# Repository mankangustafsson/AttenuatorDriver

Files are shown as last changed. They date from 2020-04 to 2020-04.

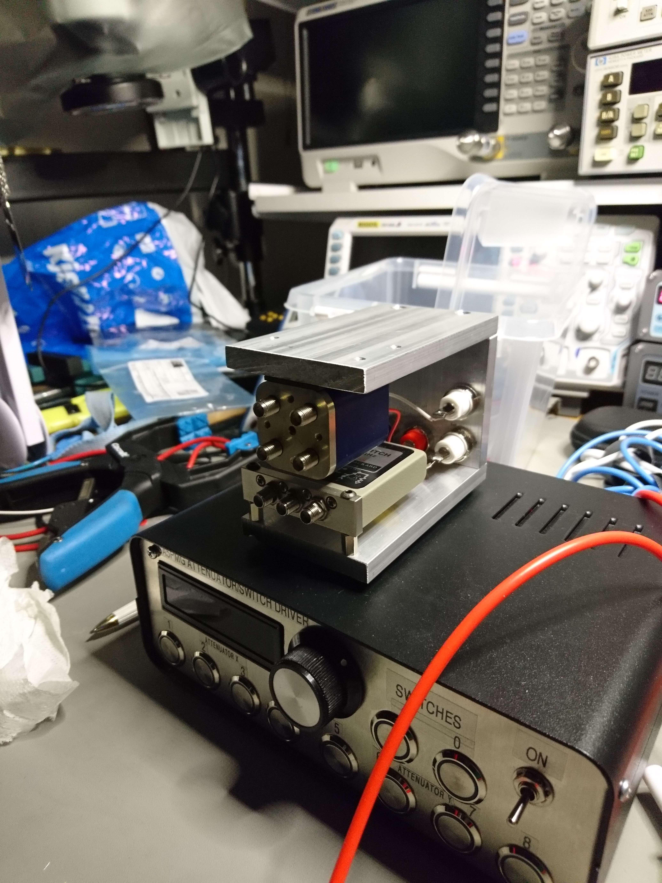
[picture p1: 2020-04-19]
gallery/build 16 relay holder done.JPG

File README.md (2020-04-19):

# AttenuatorDriver
Attenuator switch and relay driver similar to HP11713A/B. This project covers many firsts for me: First project using KiCad, first project published on github, first Python code (GPIB control) so please bear with me.

## Hardware
The HW design started out with the solenoid control of the attenuator switches inspired by the HP 33311 product overview pdf. After a while I decided to not care about the TTL output part and just trust the LED indicators.

Each attenuator solenoid is controlled by two ULN2803 outputs. 8 attenuators in total thus requires all outputs in two ULN2803:s.

To control coaxial relays I wanted to be able to handle latching relays that is controlled by polarity switching the coil voltage. For that task I found the SN754410 Quad Half-H Driver from Texas Instruments. There are cheaper circuits that can achieve this but this is the only one I found that could handle 28V coils.

To keep the micro controller I/O pin count as low as possible I decided to control the attenuators and relays drive circuits with plain old shift registers. So three 74HC595 gets the 24 output pin count down to just four.

I also wanted to keep my options open to which kind of display I would use, so that is why both I2C and SPI connectors are available. I ended up with an LCD1602 controlled via I2C. For input I wanted to mimic the HP 11713A so I wanted 10 push buttons so two R2R ladders handles five buttons each. But I also wanted to utilize the display and I find using rotary encoders with a push button quite powerful to navigate a simple UI.

### Power Supply
This can be improved but the current design works for me. The HW is fed with 12VDC and 24VDC to the ULN2803 controlling the first four attenuators. The second set of attenuators and the relays can also be feed directly with this 24V supply. Or they can have a lower voltage controlled by their individual LM317 voltage regulator. This mean that the first attenuator group decides the highest voltage that the other atteunators and relays can use.

To remedy this I would put one extra LM317 to control the voltage to the first attenuator group and remove the J6 and J7 jumpers. This way each attenuator group and the relay pair could have their coils voltages individually set.

### Patches
I made the faulty assumption about coaxial relays could control the LED the same way the attenuators did. They do not! So the remedy is to use two free micro controller pins (I use A1 and A2) to control the relay LED indicators. Depending on LEDs used the micro controller could probably drive them directly or you could still use Q3 and Q4 to sink the current. Regardless solution you select you need to remove R4 and R6.

## Arduino Software
First of all: Do not expect any compilation support from me. You are on your own. Arduino environment is messy when it comes to how it handles libraries used. I usually import the source code of the libraries I use into the project. However since I'm not the author of the [display library] I use you have to download it yourself. The current code also includes another library, Streaming, which I only used initially in this project so remove that include statement.

Second: Parts of the code is structured and easy to read. Some parts are not structured at all and poorly documented. I'm of the opinion that code should be written to be easy to understand by other programmers and therefore would not need much documentation. It is not currently in the "easy to understand" state and it might never be.

## GPIB Control
In order to avoid the Arduino being reset every time you connect to the serial port, you need to remove the capacitor between the CH340 DTR pin and the Arduino reset pin. Note that this will make it harder to upload new software to the Arduino. You will need to push the reset button manually at the proper moment during code upload.

I've written some Python code using PyVisa to control the attenuators and relays.

[display library]:       http://www.mathertel.de/Arduino/LiquidCrystal_PCF8574.aspx

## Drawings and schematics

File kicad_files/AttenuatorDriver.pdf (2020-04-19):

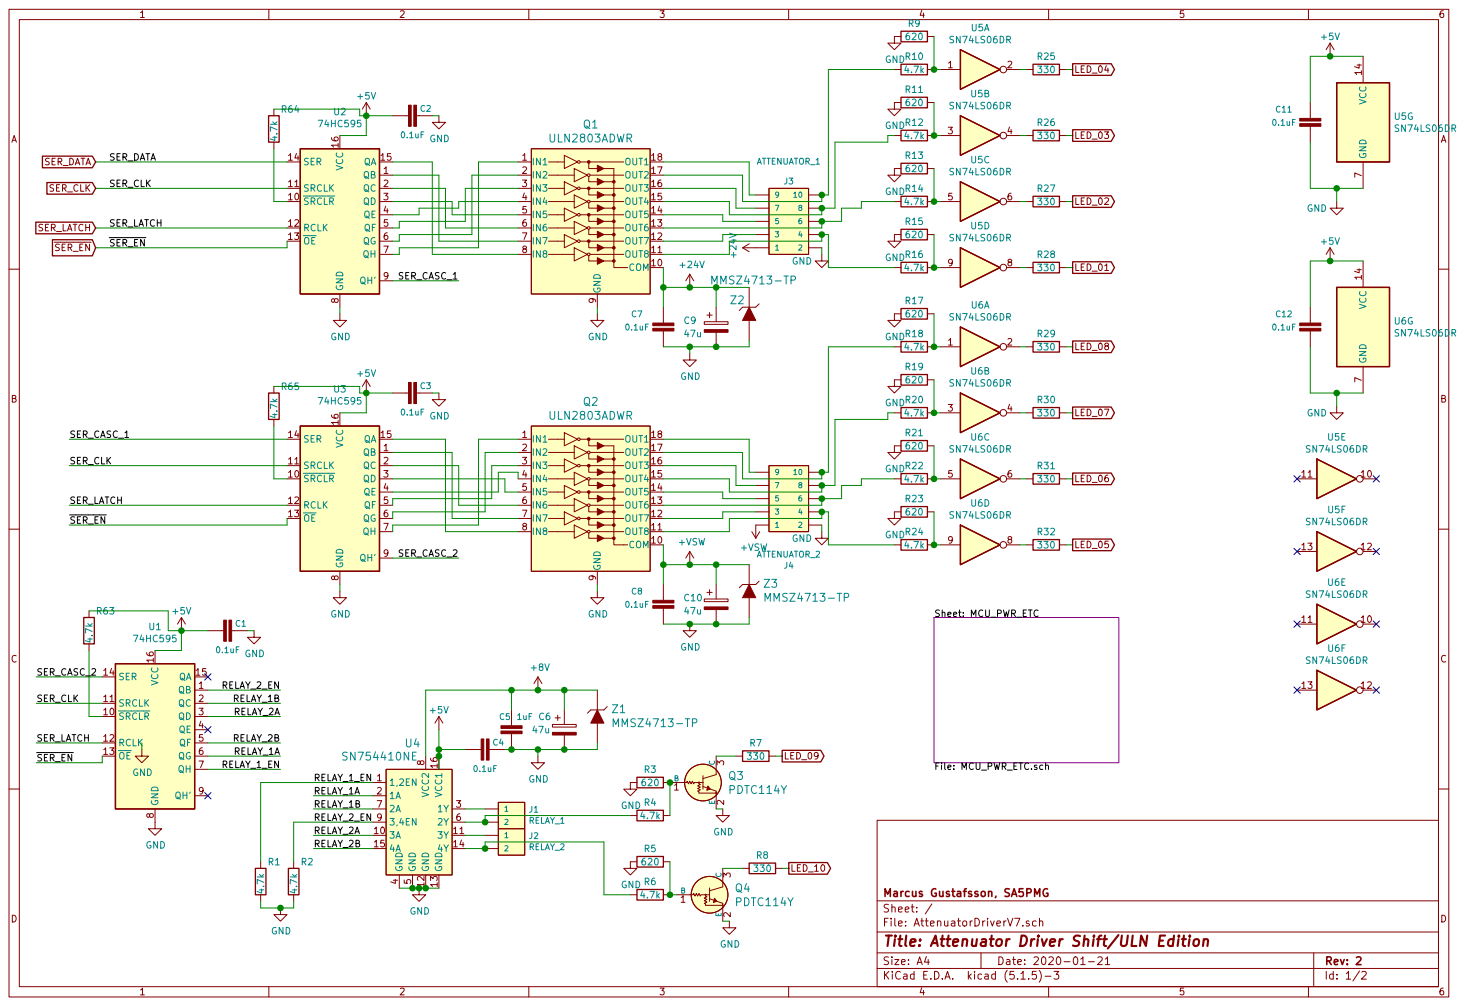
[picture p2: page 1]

File: AttenuatorDriverV7.sch Sheet: / Marcus Gustafsson, SA5PMG

Id: 1/2 Title: Attenuator Driver Shift/ULN Edition

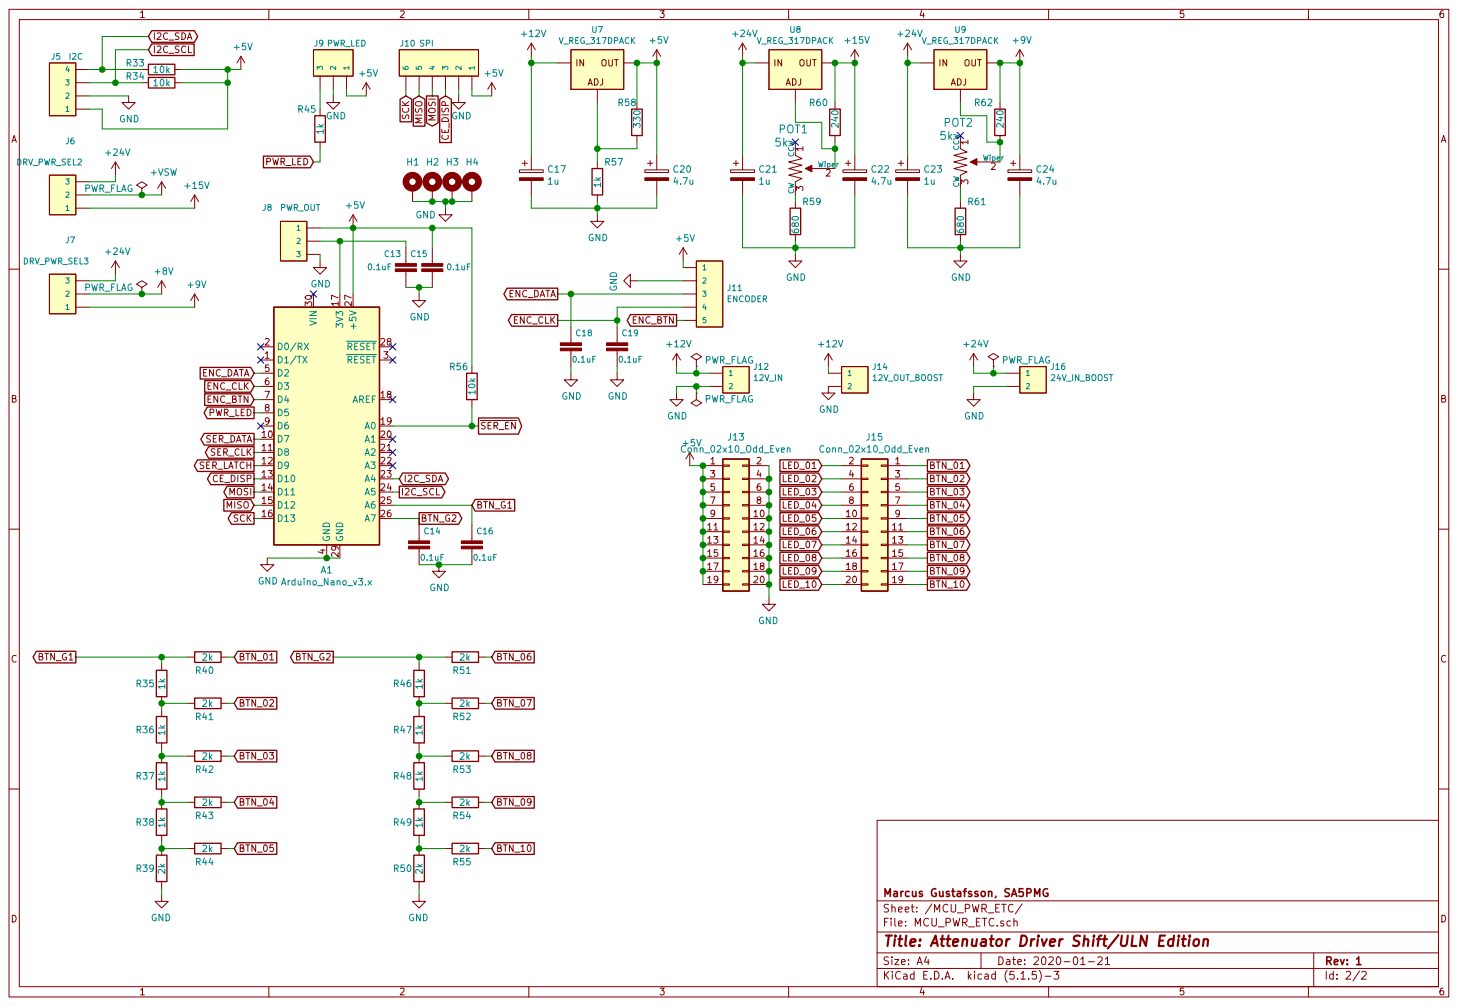
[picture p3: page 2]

11 | 12
13 | 14
15 | 16
17 | 18

Marcus Gustafsson, SA5PMG
Sheet: /MCU_PWR_ETC/
File: MCU_PWR_ETC.sch
Id: 2/2 Title: Attenuator Driver Shift/ULN Edition

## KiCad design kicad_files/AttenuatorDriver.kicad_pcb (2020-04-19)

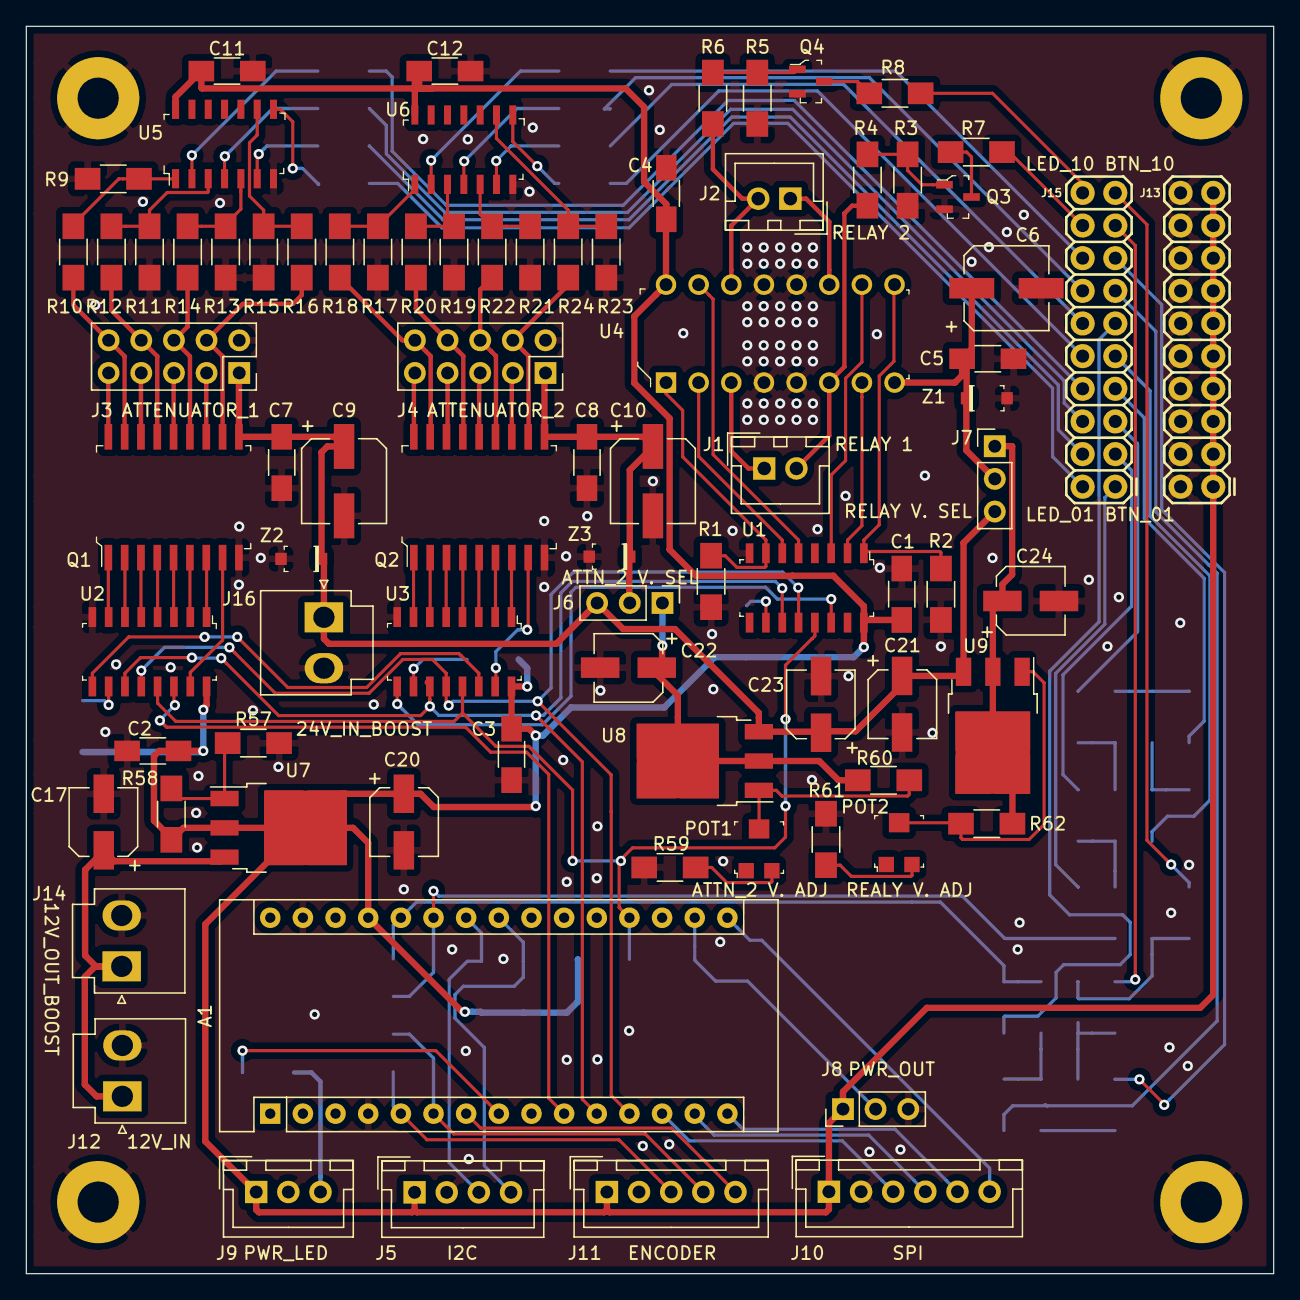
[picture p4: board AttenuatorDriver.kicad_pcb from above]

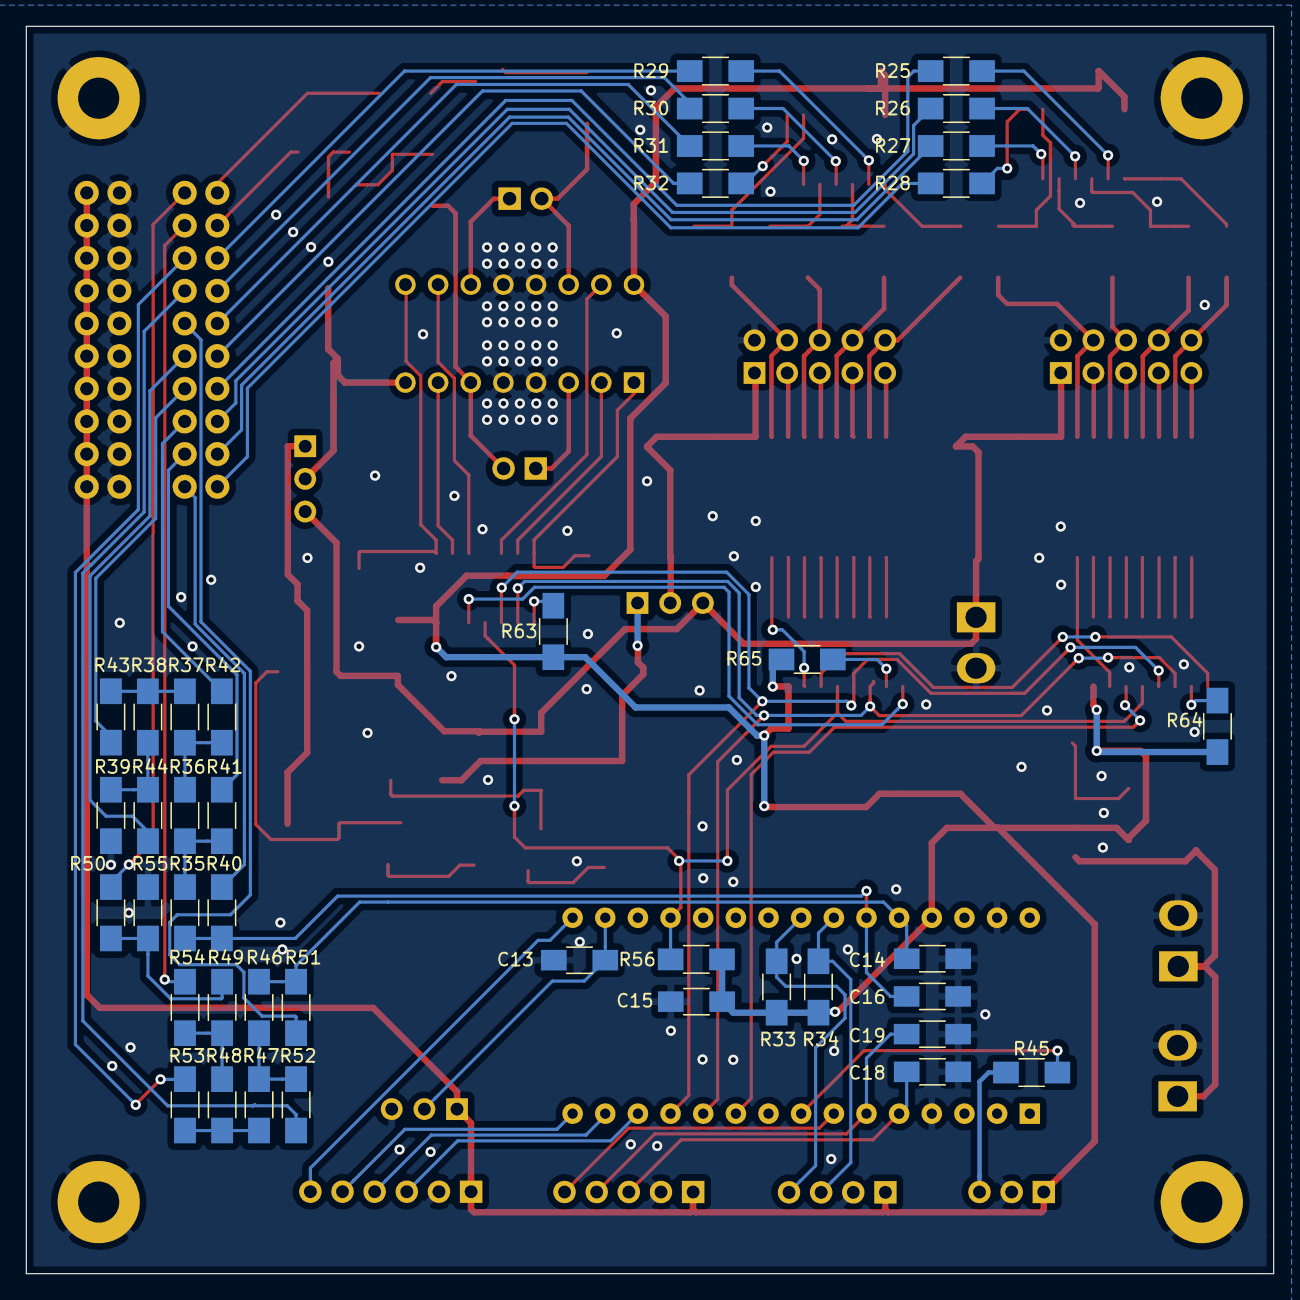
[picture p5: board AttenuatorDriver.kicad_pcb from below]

Board: 2 copper layers, 97.0 x 97.0 mm, 128 parts (41 on the bottom side), 126 nets.

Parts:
A1: Arduino_Nano_v3.x; Arduino_Nano
C1, C2, C3, C4, C7, C8, C11, C12, C13, C14, C15, C16, C18, C19: 0.1uF; C_1206_HandSoldering
C5: 1uF; C_1206_HandSoldering
C6, C9, C10: 47u; CP_Elec_6.3x7.7
C17, C21, C23: 1u; CP_Elec_5x5.3
C20, C22, C24: 4.7u; CP_Elec_5x5.3
H1, H2, H3, H4: MountingHole_Pad; MountingHole_3.2mm_M3_Pad
J1: RELAY_1; JST_XH_B02B-XH-A_02x2.50mm_Straight
J2: RELAY_2; JST_XH_B02B-XH-A_02x2.50mm_Straight
J3: ATTENUATOR_1; Socket_Strip_Straight_2x05_Pitch2.54mm
J4: ATTENUATOR_2; Socket_Strip_Straight_2x05_Pitch2.54mm
J5: I2C; JST_XH_B04B-XH-A_04x2.50mm_Straight
J6: DRV_PWR_SEL2; Pin_Header_Straight_1x03_Pitch2.54mm
J7: DRV_PWR_SEL3; Pin_Header_Straight_1x03_Pitch2.54mm
J8: PWR_OUT; Pin_Header_Straight_1x03_Pitch2.54mm
J9: PWR_LED; JST_XH_B03B-XH-A_03x2.50mm_Straight
J10: SPI; JST_XH_B06B-XH-A_06x2.50mm_Straight
J11: ENCODER; JST_XH_B05B-XH-A_05x2.50mm_Straight
J12: 12V_IN; JST_VH_B2P-VH-B_2x3.96mm_Vertical
J13, J15: Conn_02x10_Odd_Even; 2X10
J14: 12V_OUT_BOOST; JST_VH_B2P-VH-B_2x3.96mm_Vertical
J16: 24V_IN_BOOST; JST_VH_B2P-VH-B_2x3.96mm_Vertical
POT1, POT2: 5k; Trimpot_3.8mmx3.6mm_TC33X-2-103E
Q1, Q2: ULN2803ADWR; SOIC-18_W7.5mm
Q3, Q4: PDTC114Y; SOT-23-3
R1, R2, R4, R6, R10, R12, R14, R16, R18, R20, R22, R24, R63, R64, R65: 4.7k; R_1206_HandSoldering
R3, R5, R9, R11, R13, R15, R17, R19, R21, R23: 620; R_1206_HandSoldering
R7, R8, R25, R26, R27, R28, R29, R30, R31, R32, R58: 330; R_1206_HandSoldering
R33, R34, R56: 10k; R_1206_HandSoldering
R35, R36, R37, R38, R45, R46, R47, R48, R49, R57: 1k; R_1206_HandSoldering
R39, R40, R41, R42, R43, R44, R50, R51, R52, R53, R54, R55: 2k; R_1206_HandSoldering
R59, R61: 680; R_1206_HandSoldering
R60, R62: 240; R_1206_HandSoldering
U1, U2, U3: 74HC595; SOIC-16_W3.90mm
U4: SN754410NE; DIP-16_W7.62mm
U5, U6: SN74LS06DR; SOIC-14_W3.9mm
U7, U8, U9: V_REG_317DPACK; TO-252-3_TabPin2
Z1, Z2, Z3: MMSZ4713-TP; SOD-123

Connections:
+5V: A1.27, C1.1, C2.1, C3.1, C4.1, C11.1, C12.1, C15.2, C20.1, J5.1, J8.1, J9.1, J10.1, J11.1, J13.1, J13.3, J13.5, J13.7, J13.9, J13.11, J13.13, J13.15, J13.17, J13.19, R33.1, R34.1, R56.1, R58.1, R63.1, R64.1, R65.1, U1.16, U2.16, U3.16, U4.16, U5.14, U6.14, U7.2
+8V: C5.1, C6.1, J7.2, U4.8, Z1.K
+9V: C24.1, J7.1, R62.1, U9.2
+12V: C17.1, J12.1, J14.1, U7.3
+15V: C22.1, J6.1, R60.1, U8.2
+24V: C7.1, C9.1, C21.1, C23.1, J3.1, J6.3, J7.3, J16.1, Q1.10, U8.3, U9.3, Z2.K
+VSW: C8.1, C10.1, J4.1, J6.2, Q2.10, Z3.K
/RELAY_1A: U1.6, U4.2
/RELAY_1B: U1.2, U4.7
/RELAY_1_EN: R1.1, U1.7, U4.1
/RELAY_2A: U1.3, U4.10
/RELAY_2B: U1.5, U4.15
/RELAY_2_EN: R2.1, U1.1, U4.9
/SER_CASC_1: U2.9, U3.14
/SER_CASC_2: U1.14, U3.9
BTN_01: J15.1, R40.1
BTN_02: J15.3, R41.1
BTN_03: J15.5, R42.1
BTN_04: J15.7, R43.1
BTN_05: J15.9, R44.1
BTN_06: J15.11, R51.1
BTN_07: J15.13, R52.1
BTN_08: J15.15, R53.1
BTN_09: J15.17, R54.1
BTN_10: J15.19, R55.1
BTN_G1: A1.25, C16.2, R35.1, R40.2
BTN_G2: A1.26, C14.2, R46.1, R51.2
CE_DISP: A1.13, J10.3
ENC_BTN: A1.7, J11.5
ENC_CLK: A1.6, C19.2, J11.4
ENC_DATA: A1.5, C18.2, J11.3
GND: A1.4, A1.29, C1.2, C2.2, C3.2, C4.2, C5.2, C6.2, C7.2, C8.2, C9.2, C10.2, C11.2, C12.2, C13.1, C14.1, C15.1, C16.1, C17.2, C18.1, C19.1, C20.2, C21.2, C22.2, C23.2, C24.2, H1.1, H2.1, H3.1, H4.1, J3.2, J4.2, J5.2, J8.3, J9.2, J10.2, J11.2, J12.2, J13.2, J13.4, J13.6, J13.8, J13.10, J13.12, J13.14, J13.16, J13.18, J13.20, J14.2, J16.2, Q1.9, Q2.9, Q3.2, Q4.2, R1.2, R2.2, R3.2, R5.2, R9.2, R11.2, R13.2, R15.2, R17.2, R19.2, R21.2, R23.2, R39.2, R50.2, R57.2, R59.2, R61.2, U1.8, U2.8, U3.8, U4.4, U4.5, U4.12, U4.13, U5.7, U6.7, Z1.A, Z2.A, Z3.A
I2C_SCL: A1.24, J5.3, R34.2
I2C_SDA: A1.23, J5.4, R33.2
LED_01: J15.2, R28.1
LED_02: J15.4, R27.1
LED_03: J15.6, R26.1
LED_04: J15.8, R25.1
LED_05: J15.10, R32.1
LED_06: J15.12, R31.1
LED_07: J15.14, R30.1
LED_08: J15.16, R29.1
LED_09: J15.18, R7.1
LED_10: J15.20, R8.1
MISO: A1.15, J10.5
MOSI: A1.14, J10.4
unnamed: A1.17, C13.2, J8.2
unnamed: J1.1, U4.3
unnamed: J1.2, R4.2, U4.6
unnamed: J2.1, U4.11
unnamed: J2.2, R6.2, U4.14
unnamed: J3.3, Q1.12
unnamed: J3.4, Q1.11, R16.2
unnamed: J3.5, Q1.14
unnamed: J3.6, Q1.13, R14.2
unnamed: J3.7, Q1.16
unnamed: J3.8, Q1.15, R12.2
unnamed: J3.9, Q1.18
unnamed: J3.10, Q1.17, R10.2
unnamed: J4.3, Q2.12
unnamed: J4.4, Q2.11, R24.2
unnamed: J4.5, Q2.14
unnamed: J4.6, Q2.13, R22.2
unnamed: J4.7, Q2.16
unnamed: J4.8, Q2.15, R20.2
unnamed: J4.9, Q2.18
unnamed: J4.10, Q2.17, R18.2
unnamed: J9.3, R45.1
unnamed: POT1.2, R60.2, U8.1
unnamed: POT1.3, R59.1
unnamed: POT2.2, R62.2, U9.1
unnamed: POT2.3, R61.1
unnamed: Q1.1, U2.7
unnamed: Q1.2, U2.6
unnamed: Q1.3, U2.5
unnamed: Q1.4, U2.4
unnamed: Q1.5, U2.3
unnamed: Q1.6, U2.2
unnamed: Q1.7, U2.1
unnamed: Q1.8, U2.15
unnamed: Q2.1, U3.7
unnamed: Q2.2, U3.6
unnamed: Q2.3, U3.5
unnamed: Q2.4, U3.4
unnamed: Q2.5, U3.3
unnamed: Q2.6, U3.2
unnamed: Q2.7, U3.1
unnamed: Q2.8, U3.15
unnamed: Q3.1, R3.1, R4.1
unnamed: Q3.3, R7.2
unnamed: Q4.1, R5.1, R6.1
unnamed: Q4.3, R8.2
unnamed: R9.1, R10.1, U5.1
unnamed: R11.1, R12.1, U5.3
unnamed: R13.1, R14.1, U5.5
unnamed: R15.1, R16.1, U5.9
unnamed: R17.1, R18.1, U6.1
unnamed: R19.1, R20.1, U6.3
unnamed: R21.1, R22.1, U6.5
unnamed: R23.1, R24.1, U6.9
unnamed: R25.2, U5.2
unnamed: R26.2, U5.4
unnamed: R27.2, U5.6
unnamed: R28.2, U5.8
unnamed: R29.2, U6.2
unnamed: R30.2, U6.4
unnamed: R31.2, U6.6
unnamed: R32.2, U6.8
unnamed: R35.2, R36.1, R41.2
unnamed: R36.2, R37.1, R42.2
unnamed: R37.2, R38.1, R43.2
unnamed: R38.2, R39.1, R44.2
unnamed: R46.2, R47.1, R52.2
unnamed: R47.2, R48.1, R53.2
unnamed: R48.2, R49.1, R54.2
unnamed: R49.2, R50.1, R55.2
unnamed: R57.1, R58.2, U7.1
unnamed: R63.2, U1.10
unnamed: R64.2, U2.10
unnamed: R65.2, U3.10
PWR_LED: A1.8, R45.2
SCK: A1.16, J10.6
SER_CLK: A1.11, U1.11, U2.11, U3.11
SER_DATA: A1.10, U2.14
SER_LATCH: A1.12, U1.12, U2.12, U3.12
~SER_EN: A1.19, R56.2, U1.13, U2.13, U3.13

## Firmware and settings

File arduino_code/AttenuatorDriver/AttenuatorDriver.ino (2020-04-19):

#include <Streaming.h>
#include "LiquidCrystal_PCF8574.h"
#include "TButton.h"

const int SER_DATA = 7;
const int SER_CLK = 8;
const int SER_LATCH = 9;
const int SER_ENABLE = A0;

const int BUTTONS_G1 = A6;
const int BUTTONS_G2 = A7;

const int RELAY_1_LED = A1;
const int RELAY_2_LED = A2;

const int ENCODER_DATA = 2;
const int ENCODER_CLK = 3;
const int ENCODER_BTN = 4;

const int POWER_LED = 5;

const int SPI_CE = 12;

class TRelayDriver
{
public:
  TRelayDriver()
  {
    pinMode(SER_DATA, OUTPUT);
    pinMode(SER_CLK, OUTPUT);
    pinMode(SER_LATCH, OUTPUT);
    pinMode(SER_ENABLE, OUTPUT);
    digitalWrite(SER_ENABLE, LOW);
    Send(0x00, 0x00, 0x00, true);
  }

  void Set(uint8_t att1, uint8_t att2, bool relay1, bool relay2)
  {
    // char msg[100];
    // sprintf(msg, "Setting 0x%02x 0x%02x %u %u\n", att1, att2, relay1, relay2);
    // Serial << msg;
    if (att1 != Attenuator1
        || att2 != Attenuator2
        || relay1 != Relay1
        || relay2 != Relay2) {
      uint8_t relayData = 0;
      if (relay1 != Relay1) {
        relayData |= relay1 ? 0x21 : 0x03;
      }
      // Always set relay 2, and no need to pull the other way
      relayData |= relay2 ? 0x44 : 0x00; //0x50;
      // Only send changed bits for attenuators
      Send(att1 & (att1 ^ Attenuator1),
           att2 & (att2 ^ Attenuator2),
           relayData, true);
      Attenuator1 = att1;
      Attenuator2 = att2;
      Relay1 = relay1;
      Relay2 = relay2;
      // Relay 2 is non-latching so keep pulling
      relayData = Relay2 ? 0x44 : 0x00;
      delay(150);
      Send(0x00, 0x00, relayData, true);
    }
  }
private:    
  void Send(uint8_t data0, uint8_t data1, uint8_t data2, bool silent = false)
  {
    if (!CheckAttenuator(data0)
        || !CheckAttenuator(data1)
        || !CheckRelays(data2)) {
      return;
    }
    if (!silent) {
      char msg[100];
      sprintf(msg, "Sending 0x%02x 0x%02x 0x%02x\n", data0, data1, data2);
      Serial << msg;
    }
    digitalWrite(SER_LATCH, LOW);
    shiftOut(SER_DATA, SER_CLK, LSBFIRST, data2);
    shiftOut(SER_DATA, SER_CLK, LSBFIRST, data1);
    shiftOut(SER_DATA, SER_CLK, LSBFIRST, data0);
    digitalWrite(SER_LATCH, HIGH);
  }

  bool CheckAttenuator(uint8_t data)
  {
    uint8_t check = (data & (data << 1)) & 0b10101010;
    if (check != 0) {
      char msg[100];
      sprintf(msg, "Invalid attenuator setting: 0x%02x\n", data);
      Serial << msg;
      return false;
    }
    return true;
  }

  bool CheckRelays(uint8_t data)
  {
    if (((data & 0x01) != 0                // If RELAY_1_EN high
         && (data & 0x22) == 0x22)         // Both RELAY_1A and 1B can't be high
        || (((data & 0x40) != 0            // or if RELAY_2_EN high
             && (data & 0x14) == 0x14))) { // Both RELAY_2A and 2B can't be high
      char msg[100];
      sprintf(msg, "Invalid relay setting: 0x%02x\n", data);
      Serial << msg;
      return false;
    }
    return true;
  }

  uint8_t Attenuator1 = 0;
  uint8_t Attenuator2 = 0;
  bool Relay1 = false;
  bool Relay2 = false;
};

class TButtonGroup
{
public:
  TButtonGroup(int inputPin)
    : InputPin(inputPin)
  {
    pinMode(InputPin, INPUT);
    uint8_t t;
    GetStatus(t);
  }
  bool GetStatus(uint8_t& status)
  {
    unsigned long currentStamp = millis();
    int16_t v = analogRead(InputPin);
    if (abs(v - LastState) > 8) {
      LastState = v;
      StableTime = currentStamp;
    }
    else if ((currentStamp - StableTime) > 300) {
      status = 0;
      for (int16_t n = 4; n >= 0; --n) {
        uint16_t bit = 1 << (n + 5);
        if (v > (bit - 8)) {
          status |= (1 << (4-n));
          v -= (bit - 3);
          if (v < 0) {
            v = 0;
          }
        }
      }
      return true;
    }
    return false;
  }
private:
  int InputPin;
  unsigned long StableTime;
  int16_t LastState = 0;
};

TRelayDriver Driver;
LiquidCrystal_PCF8574 Display(0x27);
TButtonGroup Buttons[2] = { TButtonGroup(BUTTONS_G1),
                            TButtonGroup(BUTTONS_G2) };
uint16_t ButtonStatus = 0;
TButton EncoderButton(ENCODER_BTN, 30);

enum TMode
{
 MODE_INIT,
 MODE_BUTTONS,
 MODE_ENCODER,
 MODE_REMOTE
};

TMode Mode = MODE_INIT;
uint8_t AttenuationMap[10] = { 40, 40, 20, 10, 4, 4, 2, 1, 0, 0};
int16_t SelectAttenuation;
int16_t SelectRelays;
int16_t encoder = 0;

void CheckRemoteMessage()
{
  // Process incoming data
  String s;
  bool received = false;
  while (Serial.available() > 0 && !received) {
    char c = Serial.read();
    switch (c) {
    case 0:
    case 10:
    case ' ': // remove spaces and tabs in incoming data
    case '\t':
      break;
    case 13:
      received = true;
      break;
    default:
      s += c;
      break;
    }
  }
  if (s.length() == 0) {
    return;
  }
  Mode = MODE_REMOTE;
  UpdateDisplay(ButtonStatus);
  uint16_t buttonStatus = ButtonStatus;

  s.toUpperCase();
  //Serial << "s " << s << endl;
  while (s.length() > 0) {
    if (s.startsWith("ID") || s.startsWith("*IDN?")) {
      Serial << "HP11713AB SA5PMG edition v1.0\n";
    }
    else if (s.startsWith("PR")) {
      Mode = MODE_BUTTONS;
      buttonStatus = 0;
    }
    else if (s.startsWith("ATT")) {
      // 11713B attenuator commands here
      auto j = s.indexOf(':');
      if (j == -1) {
        goto next;
      }
      String t = s.substring(j + 1);

      if (t.startsWith("BANK1:")
          || t.startsWith(":")) {
        auto k = t.indexOf(':');
        t = t.substring(k + 1);
      }
      if (t.startsWith("X")
          || t.startsWith("Y")) {
        if (t.charAt(1) == '?') {
          int o = t.charAt(0) == 'Y' ? 4 : 0;
          unsigned int attenuation = 0;
          for (int n = 0 + o; n < 4 + o; ++n) {
            if ((buttonStatus & (1 << n)) != 0) {
              attenuation += AttenuationMap[n];
            }
          }
          Serial << "Att " << t.charAt(0) << ": " << attenuation << endl;
        }
        else {
          String as;
          for (int n = 1; n < t.length(); ++n) {
            auto c = t.charAt(n);
            if (isDigit(c)) {
              as += c;
            }
            else {
              break;
            }
          }
          if (as.length() > 0) {
            unsigned int attenuation = as.toInt();
            Serial << "Att " << t.charAt(0) << ": " << attenuation << endl;
            if (t.charAt(0) == 'X'
                && (attenuation % 10) == 0
                && attenuation <= 110) {
              for (int n = 0; n < 4; ++n) {
                if (attenuation >= AttenuationMap[n]) {
                  buttonStatus |= (1 << n);
                  attenuation -= AttenuationMap[n];
                }
                else {
                  buttonStatus &= 0xffff ^ (1 << n);
                }
              }
            }
            else if (t.charAt(0) == 'Y'
                     && attenuation <= 11) {
              for (int n = 4; n < 8; ++n) {
                if (attenuation >= AttenuationMap[n]) {
                  buttonStatus |= (1 << n);
                  attenuation -= AttenuationMap[n];
                }
                else {
                  buttonStatus &= 0xffff ^ (1 << n);
                }
              }
            }
          }
        }
      }
    }
    else if (s.startsWith(":ROUT")
             || s.startsWith(":CLOS")
             || s.startsWith(":OPE")) {
      // 11713B switch(relay) commands here
      auto i = s.indexOf('@');
      if (i == -1) {
        goto next;
      }
      bool closing = false;
      bool found = false;
      if (s.indexOf(":CLOS") != -1) {
        closing = true;
        found = true;
      }
      if (s.indexOf(":OPE") != -1) {
        found = true;
        if (closing) {
          goto next;
        }
      }
      if (!found) {
        goto next;
      }
      String t = s.substring(i + 1);
      auto j = t.indexOf(':');
      if (j == -1) {
        // explicit channels
        for (int n = 0; n < t.length() - 3; n += 4) {
          int channel = t.substring(n, n + 3).toInt() - 101;
          if (channel >= 0 && channel < 10) {
            if (closing) {
              buttonStatus |= (1 << channel);
            }
            else {
              buttonStatus &= 0xffff ^ (1 << channel);
            }
          }
        }
      }
      else {
        // channel range
        int from = t.substring(0, j).toInt() - 101;
        if (from >= 0 && (j + 4) <= t.length()) {
          int to = t.substring(j + 1, j + 4).toInt() - 101;
          if (to < 10) {
            for (int n = from; n <= to; ++n) {
              if (closing) {
                buttonStatus |= (1 << n);
              }
              else {
                buttonStatus &= 0xffff ^ (1 << n);
              }
            }
          }
        }
      }
    }
    else {
      // 11713A Ax By commands
      int on = 0;
      int off = 0;
      enum TState { CMD, ON, OFF, END };
      TState state = CMD;

      for (int n = 0; n < s.length(); ++n) {
        char c = s.charAt(n);
        switch (state) {
        case CMD:
          switch (c) {
          case 'A':
            state = ON;
            break;
          case 'B':
            state = OFF;
            break;
          default:
            state = END;
            break;
          }
          break;
        case ON:
        case OFF:
          if (isDigit(c)) {
            uint16_t bit = c - '0';
            bit = bit == 0 ? 9 : --bit;
            if (state == ON) {
              buttonStatus |= (1 << bit);
            }
            else {
              buttonStatus &= (0xffff ^ (1 << bit));
            }
          }
          else {
            state = CMD;
            --n;
          }
          break;
        case END:
          n += s.length();
          //Serial << "Parse error at " << n << " in " << as << endl;
          break;
        }
      }
    }
  next:
    auto i = s.indexOf(';');
    if (i == -1) {
      break;
    }
    s = s.substring(i + 1);
  }

  if (buttonStatus != ButtonStatus) {
    SetOutputs(buttonStatus);
    UpdateDisplay(buttonStatus);
    ButtonStatus = buttonStatus;
  }
}

void setup()
{
  analogReference(DEFAULT);
  pinMode(RELAY_1_LED, OUTPUT);
  digitalWrite(RELAY_1_LED, LOW);
  pinMode(RELAY_2_LED, OUTPUT);
  digitalWrite(RELAY_2_LED, LOW);
  pinMode(ENCODER_DATA, INPUT_PULLUP);
  pinMode(ENCODER_CLK, INPUT_PULLUP);
  attachInterrupt(digitalPinToInterrupt(ENCODER_CLK), update_encoder, CHANGE);
  attachInterrupt(digitalPinToInterrupt(ENCODER_DATA), update_encoder, CHANGE);
  pinMode(POWER_LED, OUTPUT);
  digitalWrite(POWER_LED, HIGH);
  pinMode(SPI_CE, OUTPUT);
  digitalWrite(SPI_CE, LOW);
  Serial.begin(115200);
  Display.begin(16,2);
  Display.setBacklight(255);
  Display.print("SA5PMG HP11713AB");
  Display.setCursor(0, 1);
  Display.print(__DATE__);
  delay(1200);
}

void UpdateDisplay(uint16_t buttonStatus)
{
  String buttonString;
  uint8_t attenuation = 0;
  for (int n = 0; n < 10; ++n) {
    if ((buttonStatus & (1 << n)) != 0) {
      buttonString += String((n + 1) % 10, DEC);
      attenuation += AttenuationMap[n];
    }
    else {
      buttonString += ' ';
    }
    if ((n + 1) % 4 == 0) {
      buttonString += ' ';
    }
  }
  switch (Mode) {
  case MODE_INIT:
    Mode = MODE_BUTTONS;
    // fall thru
  case MODE_BUTTONS:
    buttonString += " BTN";
    break;
  case MODE_ENCODER:
    buttonString += " ENC";
    break;
  case MODE_REMOTE:
    buttonString += " REM";
    break;
  }
  char msg[100];
  sprintf(msg, "Attenuation: %3d\0", attenuation);
  Display.noCursor();
  Display.setCursor(0, 0);
  Display.print(msg);
  Display.setCursor(0, 1);
  Display.print(buttonString);
}

uint8_t ConvertToAttenuator(uint8_t buttonStatus)
{
  if ((buttonStatus & 0xf0) != 0) {
    Serial << "Invalid button status " << buttonStatus << endl;
    return 0;
  }
  uint8_t attenuator = 0;
  for (int n = 0; n < 4; ++n) {
    attenuator |= (buttonStatus & (1 << n)) != 0 ?
      1 << (7 - (2 * n + 1)) : 1 << (7 - 2 * n);
  }
  return attenuator;
}

void SetOutputs(uint16_t buttonStatus)
{
  uint8_t att1 = ConvertToAttenuator(buttonStatus & 0x0f);
  uint8_t att2 = ConvertToAttenuator((buttonStatus >> 4) & 0x0f);
  bool relay1 = buttonStatus & 0x100;
  bool relay2 = buttonStatus & 0x200;
  digitalWrite(RELAY_1_LED, relay1 ? HIGH : LOW);
  digitalWrite(RELAY_2_LED, relay2 ? HIGH : LOW);
  Driver.Set(att1, att2, relay1, relay2);
}

inline int8_t read_encoder()
{
  int8_t enc_states[] = {0,-1,1,0,1,0,0,-1,-1,0,0,1,0,1,-1,0};
  static uint8_t old_AB = 0;
  old_AB <<= 2;                 
  old_AB |= ( (PIND >> 2) & 0x03 );
  return enc_states[(old_AB & 0x0f)];
}

void update_encoder()
{
  encoder -= read_encoder();
}

bool read_button()
{
  static bool s = false;
  bool b = EncoderButton.Test();
  if (b != s) {
    s = b;
    if (!s) {
      return true;
    }
  }
  return false;
}

enum TEncoderState
{
   STATE_ATT,
   STATE_RELAY,
   STATE_SET
};
TEncoderState EncoderState;
enum TEncoderSetState
{
   SET_OK,
   SET_CANCEL,
   SET_EXIT
};
TEncoderSetState EncoderSetState = SET_OK;

void EnterEncoderMode()
{
  Mode = MODE_ENCODER;
  EncoderState = STATE_ATT;
  EncoderSetState = SET_OK;
  SelectAttenuation = 0;
  for (int n = 0; n < 8; ++n) {
    if ((ButtonStatus & (1 << n)) != 0) {
      SelectAttenuation += AttenuationMap[n];
    }
  }
  SelectRelays = ButtonStatus & 0x300;
}

void loop()
{
  uint8_t b1;
  uint8_t b2;
  uint16_t buttonStatus = ButtonStatus;
  if (Buttons[0].GetStatus(b1)
      && Buttons[1].GetStatus(b2)) {
    buttonStatus = (b2 << 5) | b1;
  }
  if (Mode == MODE_INIT
      || (Mode == MODE_BUTTONS
          && buttonStatus != ButtonStatus)) {
    ButtonStatus = buttonStatus;
    if (Mode == MODE_BUTTONS) {
      SetOutputs(buttonStatus);
    }
    UpdateDisplay(buttonStatus);
  }
  CheckRemoteMessage();

  bool updateScreen = false;
  bool buttonClick = read_button();
  if (buttonClick && Mode != MODE_ENCODER) {
    EnterEncoderMode();
    buttonClick = false;
    updateScreen = true;
  }

  if (Mode == MODE_ENCODER) {
    if (buttonClick) {
      updateScreen = true;
      switch (EncoderState) {
      case STATE_ATT:
        EncoderState = STATE_RELAY;
        break;
      case STATE_RELAY:
        EncoderState = STATE_SET;
        break;
      case STATE_SET:
        switch(EncoderSetState) {
        case SET_OK:
          {
            buttonStatus = 0;
            int16_t attenuation = SelectAttenuation;
            for (int n = 0; n < 8; ++n) {
              if (attenuation >= AttenuationMap[n]) {
                buttonStatus |= (1 << n);
                attenuation -= AttenuationMap[n];
              }
              else {
                buttonStatus &= (0xffff ^ (1 << n));
              }
            }
            buttonStatus |= SelectRelays;
            if (buttonStatus != ButtonStatus) {
              ButtonStatus = buttonStatus;
              SetOutputs(buttonStatus);
            }
            EncoderState = STATE_ATT;
          }
          break;
        case SET_CANCEL:
          EnterEncoderMode();
          break;
        case SET_EXIT:
          Mode = MODE_INIT;
          goto end_of_loop;
          break;
        }
      }
    }
    static uint16_t current = 0;
    int16_t delta = (encoder - current);
    if (delta != 0 && !buttonClick) {
      updateScreen = true;
      current = encoder;
      switch (EncoderState) {
      case STATE_ATT:
        SelectAttenuation += delta;
        SelectAttenuation = SelectAttenuation > 121 ? 121 : SelectAttenuation;
        SelectAttenuation = SelectAttenuation < 0 ? 0 : SelectAttenuation;
        break;
      case STATE_RELAY:
        if (delta > 0) {
          SelectRelays = (SelectRelays + 0x100) & 0x300;
        }
        else {
          SelectRelays = (SelectRelays - 0x100) & 0x300;
        }
        break;
      case STATE_SET:
        switch (EncoderSetState) {
        case SET_OK:
          EncoderSetState = (delta > 0) ? SET_CANCEL : SET_EXIT;
          break;
        case SET_CANCEL:
          EncoderSetState = (delta > 0) ? SET_EXIT : SET_OK;
          break;
        case SET_EXIT:
          EncoderSetState = (delta > 0) ? SET_OK : SET_CANCEL;
          break;
        }
      }
    }
    if (updateScreen) {
      char msg[100];
      sprintf(msg, "Attenuation: %3d\0", SelectAttenuation);
      Display.cursor();
      Display.setCursor(0, 0);
      Display.print(msg);
      Display.setCursor(0, 1);
      Display.print("Switch:");
      Display.print(SelectRelays & 0x100 ? '9' : '_');
      Display.print(SelectRelays & 0x200 ? '0' : '_');
      switch (EncoderSetState) {
      case SET_OK: 
        Display.print("    Set");
        break;
      case SET_CANCEL:
        Display.print(" Cancel");
        break;
      case SET_EXIT:
        Display.print("   Exit");
        break;
      }
      switch (EncoderState) {
      case STATE_ATT:
        Display.setCursor(15, 0);
        break;
      case STATE_RELAY:
        Display.setCursor(6, 1);
        break;
      case STATE_SET:
        Display.setCursor(15, 1);
        break;
      }
    }
  }
 end_of_loop:
  delay(20);
}

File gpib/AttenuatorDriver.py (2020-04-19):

import pyvisa

class AttenuatorDriver:
    def __init__(self, verbose = True):
        rm = pyvisa.ResourceManager()
        address = 'ASRL34::INSTR'
        self.dev = rm.open_resource(address, baud_rate = 115200)
        self.verbose = verbose
        self.dev.timeout = 5000
        self.dev.read_termination = '\n'
        self.dev.write_termination = '\n'
        if verbose:
            print('Connecting to ' + address + '...',
                  end ='', flush = True)
        name = self.dev.query('*IDN?')
        if verbose: print('connected to ' + name)

    def __del__(self):
        self.dev.close()
 
    def preset(self):
        self.dev.write('PR')

    def setAttenuation(self, db):
        if db < 0 or db > 121:
            raise ValueError('Attenuation out of range: %u' %db)
        x = (db // 10) * 10
        if x == 120:
            x = 110
        y = db - x
        cmd = 'ATT:BANK1:X%d' % x
        cmd += ';ATT:BANK1:Y%d' % y
        self.dev.write(cmd)

    def getAttenuation(self):
        x = self.dev.query('ATT:BANK1:X?');
        y = self.dev.query('ATT:BANK1:Y?');
        return int(x.split(':')[1]) + int(y.split(':')[1])

    def __setRelay(self, op, relay):
        if relay not in [0, 9, 10]:
            raise ValueError('Invalid relay: %d' %relay)
        r = relay + 100
        if r == 100:
            r += 10
        self.dev.write(':ROUTe:%s (@%d)' %(op, r))

    def openRelay(self, relay):
        self.__setRelay('OPEn', relay)

    def closeRelay(self, relay):
        self.__setRelay('CLOSe', relay)

        
